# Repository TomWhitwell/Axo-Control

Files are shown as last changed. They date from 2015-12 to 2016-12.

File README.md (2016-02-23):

# Control board for Axoloti 

This is an unnoficial knob board for the [Axoloti Core board](http://www.axoloti.com/).  It is not authorised or approved by Axoloti. 

Quick demo video: https://www.instagram.com/p/BAqbNhdjmaf/   
Another demo video: https://www.youtube.com/watch?v=lhx-O6MQIug  

##BOM  
1 x PS2/3 analogue joystick, available from [Sparkfun](https://www.sparkfun.com/products/9032) or [Cool Components](https://www.coolcomponents.co.uk/thumb-joystick.html)  

6 x 10k Potentiometers
- 9mm vertical pots 
- Linear taper, any value from 5k to 50k should be fine
- D Shaft (or whatever is suitable for your knobs)
- Try: Bourns PTV09A-4020F-B103 or Alps RK09K1130C79
- Or Alpha 9mm from [Thonk](https://www.thonk.co.uk/shop/alpha-9mm-pots/) 
- NB: If you can't find the Joystick, there is a space for a 7th pot underneath

3 x 12mm square tactile switches
- Multicomp MCDTS2-4R is the right switch, but it seems to be a fairly standard layout 
- The board also has space for standard little 6mm tactile switches
- You can get keycaps for the Omron 12mm switches:Black: KTSC-21K, White: KTSC-21I, Yellow: KTSC-21Y, Red: KTSC-21R. (

4 x 1k Resistors for LEDs (use higher values - 5k to 10k if you have ultrabright LEDs) 

4 x 3mm LEDs

4 x 11mm M3 Hex Standoffs to connect the control board to the main Axoloti Core PCB

*NB: Ignore these headers: The way the board has come out, it's impossible to solder them in, and the board is perfectly strong without them.*  2 x 2 pin Female Header 571-215297-2 to mount on the back of the Control board to provide support by connecting to pins on the X3 and X4 headers. There is no electrical connection here. 

1 x 40 pin Female Header to mount on the Axoloti core 

1 x 40 pin Male Header to mount on the Control board

##STATUS 
January 2016: Board built, works well. OSHPark project here: https://oshpark.com/shared_projects/XJm2ysZW  
Video here: https://www.instagram.com/p/BAqbNhdjmaf/   
December 2015: Design completed for Rev1 board, prototypes ordered from OSH Park. Design, BOM, Layout NOT VERIFIED. 

##LICENSE 
This project is Open Hardware  
All hardware and software design in this project is Creative Commons licensed by Tom Whitwell: CC-BY-SA: Attribution / ShareAlike.  
If you use any work in this project, you should credit me, and you must republish any changes you make under the same license.  
This license does permit commercial use of these designs, but consider getting in touch before selling anything.  
This license does not include or imply any connection to the Axoloti project by Johannes Taelman.

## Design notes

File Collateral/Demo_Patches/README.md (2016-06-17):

Axoloti Control Demo Patches 

If you compile these 3 onto your SD card, set to load 1 automatically, you should be able to switch between the patches by pushing one of the tiny buttons on the back of the board. 

These are super rough but might be useful for someone. I think 1.axp requires the audio files from a Radio Music module SD card to work.

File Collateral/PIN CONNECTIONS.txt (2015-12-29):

ANALOG INS

PA0
PA1
PA2
PA3
PA4
PA5
PA6
PA7 

PWM LED OUTS 
PB0
PB1
PB8
PB9 

DIGITAL INS BUTTONS
PC0
PC1
PC2
PC3

UNUSED: 
PC5 - DIGI IN DIGI OUT 
PC4 - DIGI IN DIGI OUT ANALOG IN 
PB7 - DIGI IN DIGI OUT 
PB6 - DIGI IN DIGI OUT

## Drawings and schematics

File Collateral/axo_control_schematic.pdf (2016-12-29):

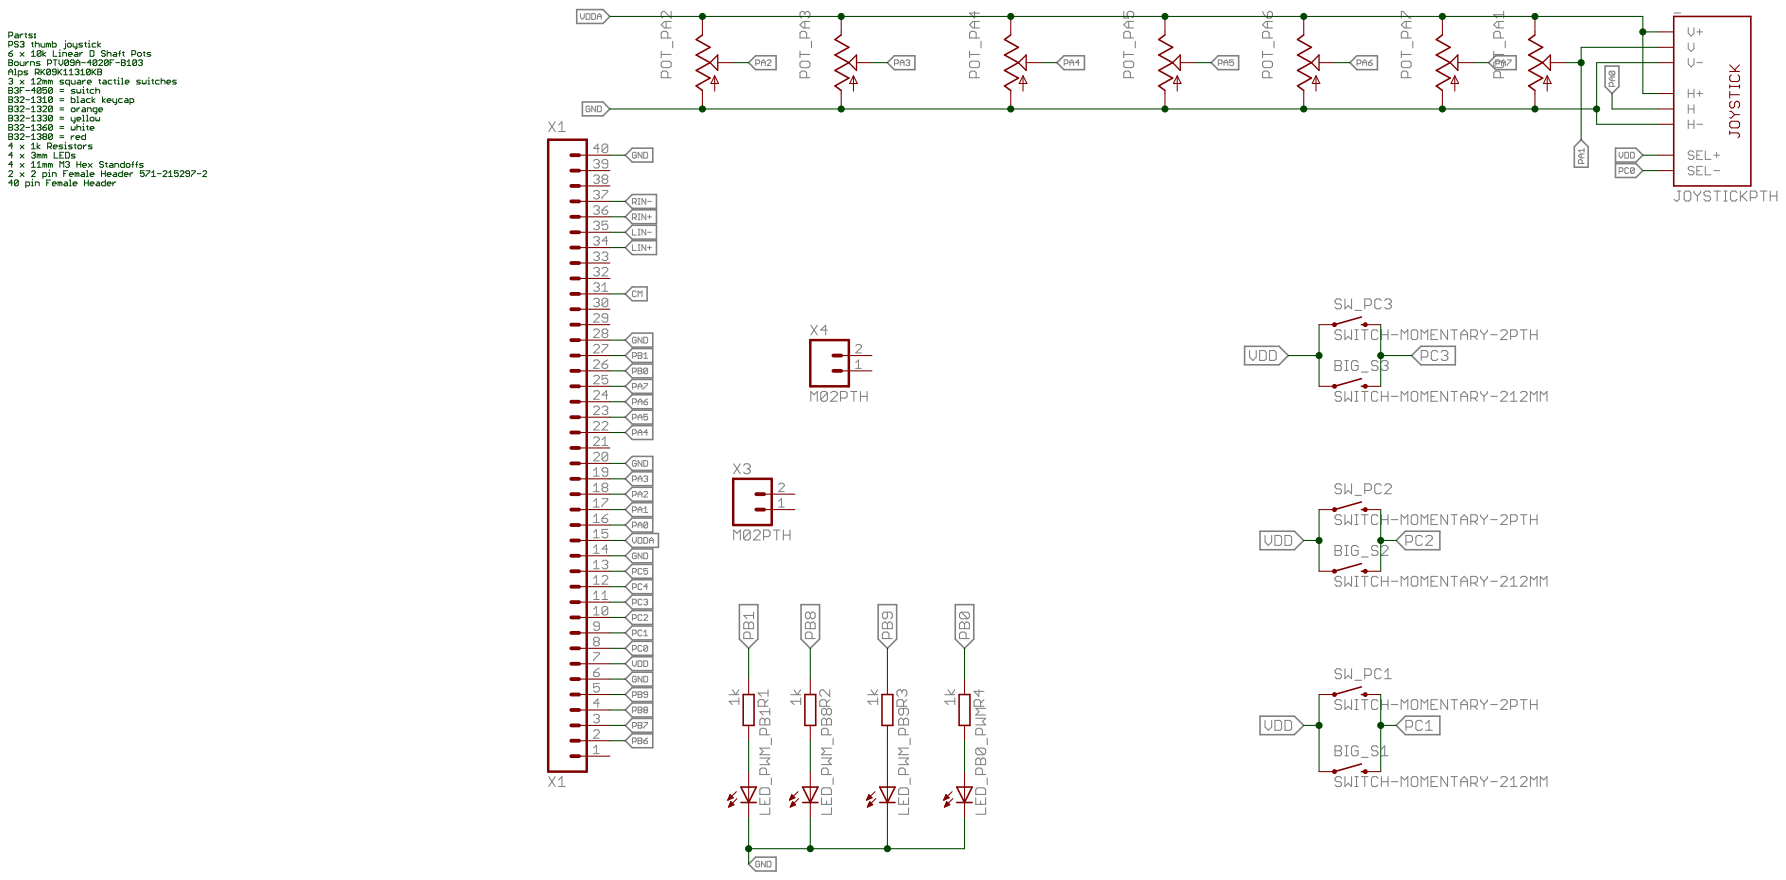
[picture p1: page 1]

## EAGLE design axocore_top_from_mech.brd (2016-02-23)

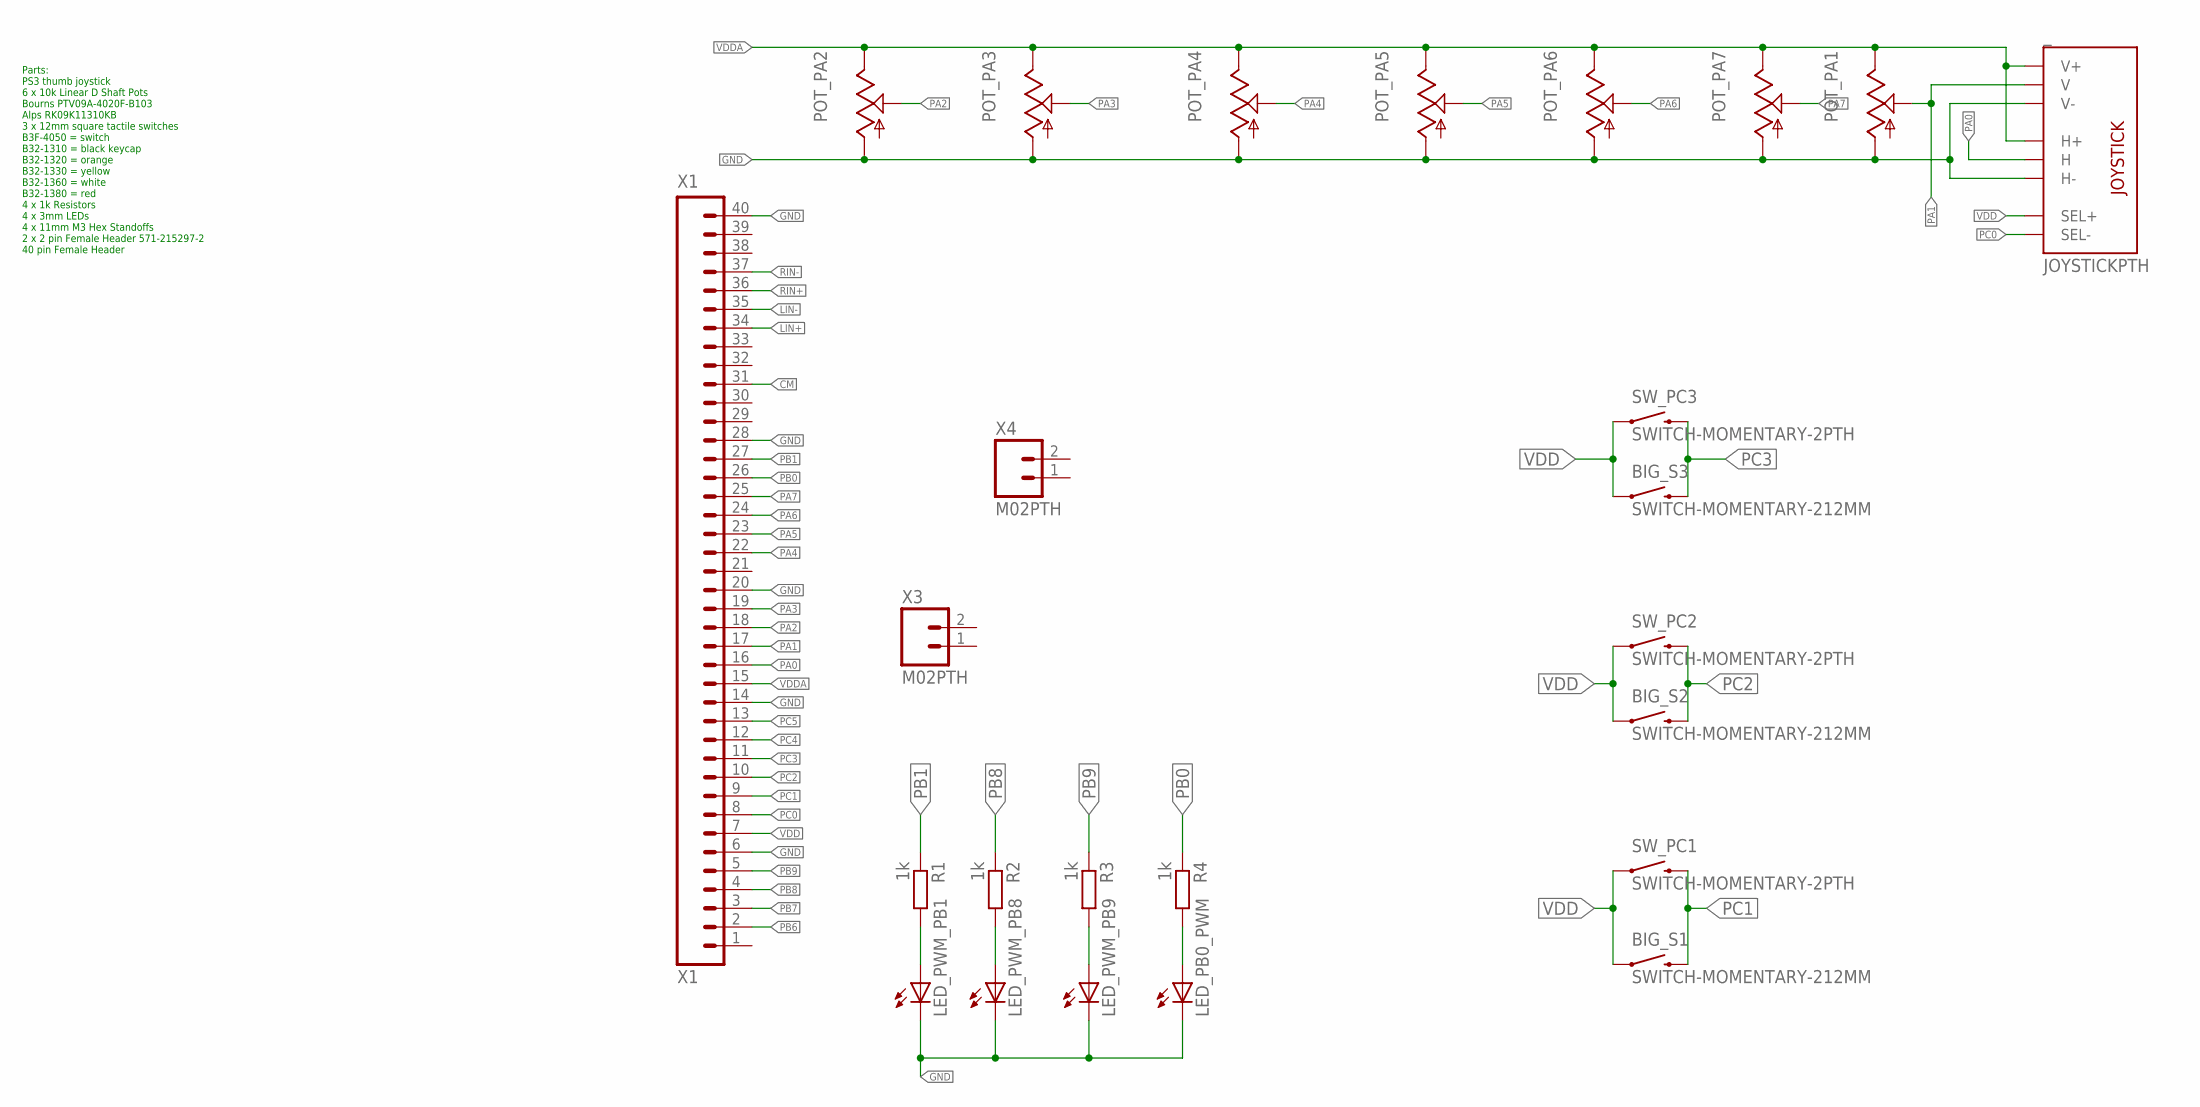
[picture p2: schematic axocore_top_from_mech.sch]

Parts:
BIG_S1, BIG_S2, BIG_S3: SWITCH-MOMENTARY-212MM; TACTILE-PTH-12MM
LED_PB0_PWM: LED3MM
LED_PWM_PB1, LED_PWM_PB8, LED_PWM_PB9: LED3MM
POT_PA1, POT_PA2, POT_PA3, POT_PA4, POT_PA5, POT_PA6, POT_PA7: 9MM_SNAP-IN_POT_; 9MM_SNAP-IN_POT
R1, R2, R3, R4: 1k; 7MM_RESISTOR
SW_PC1, SW_PC2, SW_PC3: SWITCH-MOMENTARY-2PTH; TACTILE-PTH
X1: X1; 1X40
X3, X4: M02PTH; 1X02
_: JOYSTICKPTH; JOYSTICK

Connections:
CM: X1.31
GND: LED_PB0_PWM.K (C), LED_PWM_PB1.K (C), LED_PWM_PB8.K (C), LED_PWM_PB9.K (C), POT_PA1.1 (A), POT_PA2.1 (A), POT_PA3.1 (A), POT_PA4.1 (A), POT_PA5.1 (A), POT_PA6.1 (A), POT_PA7.1 (A), X1.6, X1.14, X1.20, X1.28, X1.40, _.H3 (H-), _.V3 (V-)
LIN+: X1.34
LIN-: X1.35
unnamed: LED_PWM_PB1.A, R1.2
unnamed: LED_PWM_PB8.A, R2.2
unnamed: LED_PWM_PB9.A, R3.2
unnamed: LED_PB0_PWM.A, R4.2
PA0: X1.16, _.H2 (H)
PA1: POT_PA1.2 (S), X1.17, _.V2 (V)
PA2: POT_PA2.2 (S), X1.18
PA3: POT_PA3.2 (S), X1.19
PA4: POT_PA4.2 (S), X1.22
PA5: POT_PA5.2 (S), X1.23
PA6: POT_PA6.2 (S), X1.24
PA7: POT_PA7.2 (S), X1.25
PB0: R4.1, X1.26
PB1: R1.1, X1.27
PB6: X1.2
PB7: X1.3
PB8: R2.1, X1.4
PB9: R3.1, X1.5
PC0: X1.8, _.B2A (SEL-)
PC1: BIG_S1.3 (2), SW_PC1.3 (2), X1.9
PC2: BIG_S2.3 (2), SW_PC2.3 (2), X1.10
PC3: BIG_S3.3 (2), SW_PC3.3 (2), X1.11
PC4: X1.12
PC5: X1.13
RIN+: X1.36
RIN-: X1.37
VDD: BIG_S1.1, BIG_S2.1, BIG_S3.1, SW_PC1.1, SW_PC2.1, SW_PC3.1, X1.7, _.B1A (SEL+)
VDDA: POT_PA1.3 (E), POT_PA2.3 (E), POT_PA3.3 (E), POT_PA4.3 (E), POT_PA5.3 (E), POT_PA6.3 (E), POT_PA7.3 (E), X1.15, _.H1 (H+), _.V1 (V+)

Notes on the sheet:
Parts: PS3 thumb joystick 6 x 10k Linear D Shaft Pots Bourns PTV09A-4020F-B103 Alps RK09K11310KB 3 x 12mm square tactile switches B3F-4050 = switch B32-1310 = black keycap B32-1320 = orange B32-1330 = yellow B32-1360 = white B32-1380 = red 4 x 1k Resistors 4 x 3mm LEDs 4 x 11mm M3 Hex Standoffs 2 x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

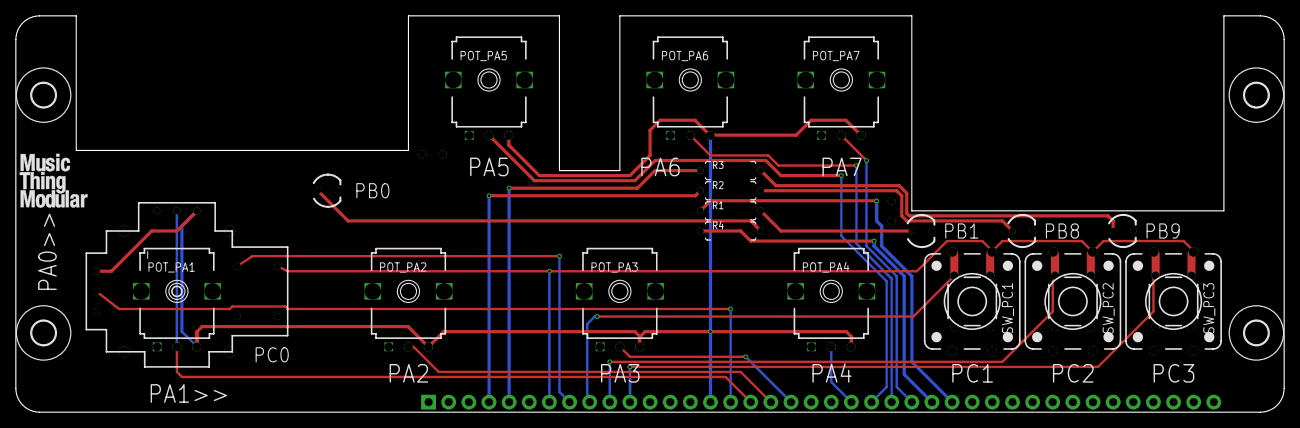
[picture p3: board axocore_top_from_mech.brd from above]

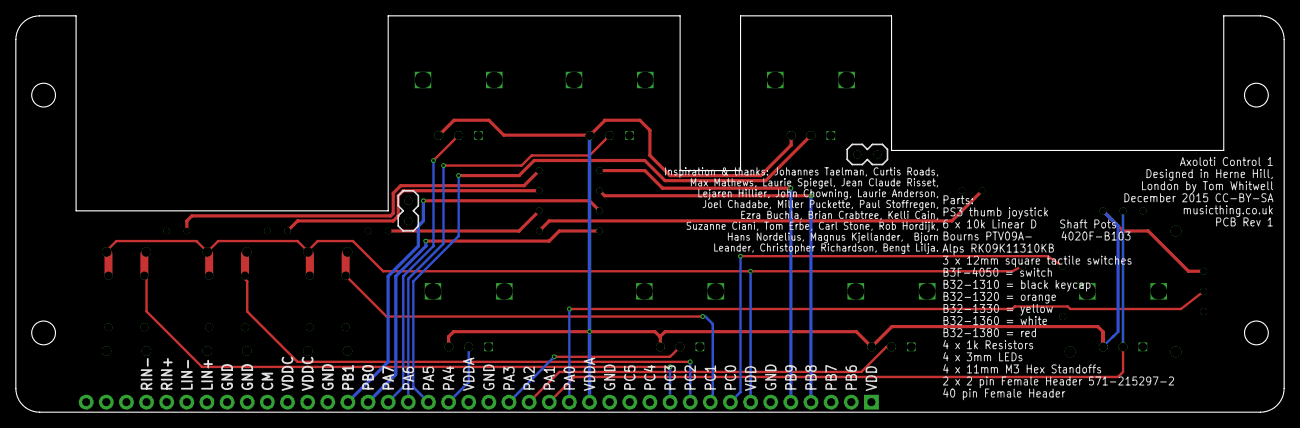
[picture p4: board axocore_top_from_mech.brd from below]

Board: 4 copper layers, 160.0 x 50.0 mm, 29 parts (2 on the bottom side), 23 nets.

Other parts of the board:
H1, H2, H4, H6: MOUNT-HOLE3.0; 3,0

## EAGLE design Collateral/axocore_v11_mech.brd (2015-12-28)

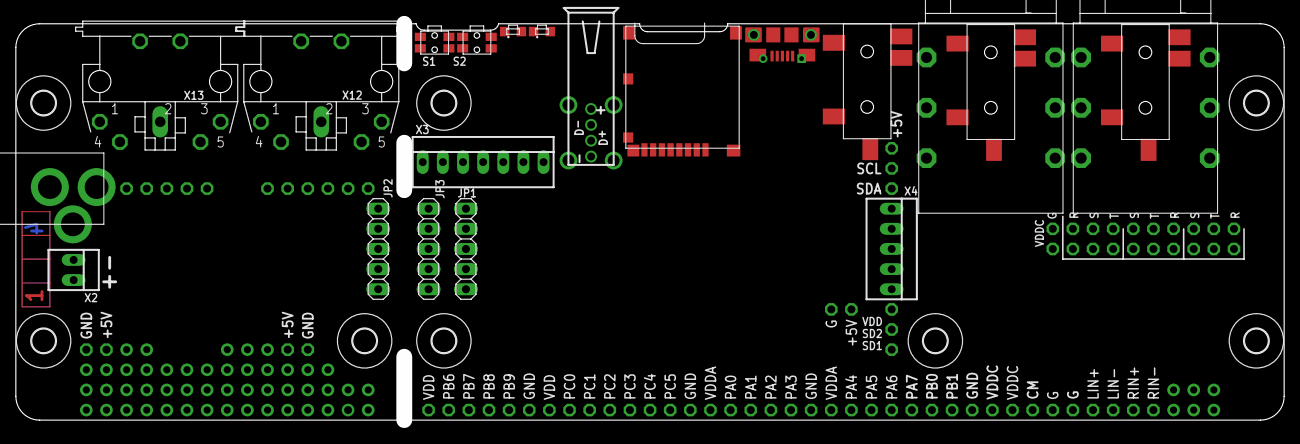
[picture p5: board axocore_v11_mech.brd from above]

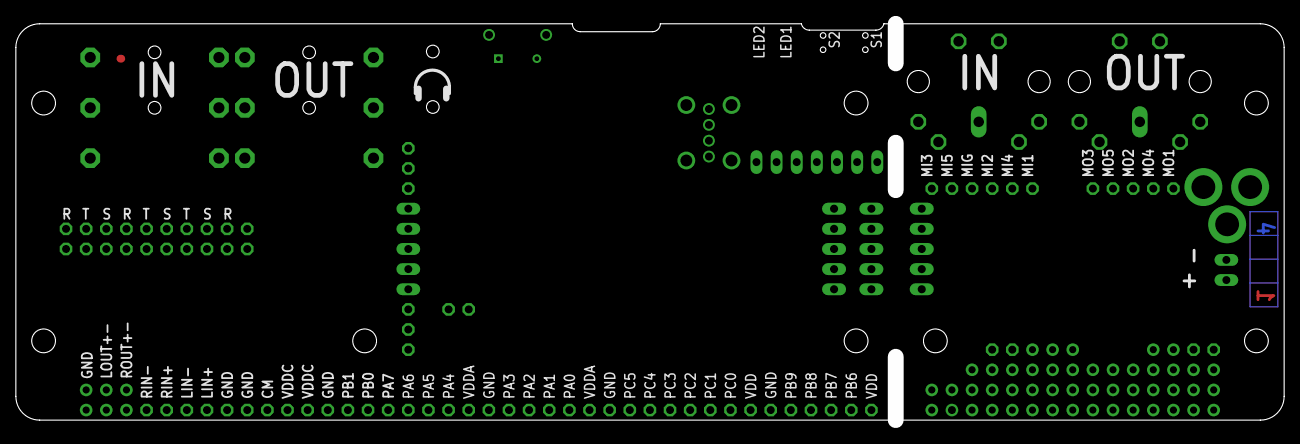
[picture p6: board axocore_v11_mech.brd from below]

Board: 2 copper layers, 160.0 x 50.0 mm, 109 parts (11 on the bottom side), 31 nets.

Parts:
D5: SML-A12 RED; SML-A12
D6: SML-A12 GREEN; SML-A12
H1, H2, H3, H4, H5, H6, H7, H8: MOUNT-HOLE3.0; 3,0
JP1: 1X05
JP2, JP3: NC; 1X05
S1, S2: EVQP7
TP1, TP66, TP77: VDDC; PROTOHOLE_NAMED
TP2: MI3; PROTOHOLE_NAMED
TP3: MI5; PROTOHOLE_NAMED
TP4: CM; PROTOHOLE_NAMED
TP5: MI1; PROTOHOLE_NAMED
TP6: MI4; PROTOHOLE_NAMED
TP7, TP59, TP63, TP67: G; PROTOHOLE_NAMED
TP8: MI2; PROTOHOLE_NAMED
TP9: MIG; PROTOHOLE_NAMED
TP10: MO3; PROTOHOLE_NAMED
TP11: MO1; PROTOHOLE_NAMED
TP12: MO5; PROTOHOLE_NAMED
TP13, TP57, TP58, TP60, TP61, TP62: GND; PROTOHOLE_NAMED
TP14: SD1; PROTOHOLE_NAMED
TP15: SD2; PROTOHOLE_NAMED
TP16, TP64, TP65: VDD; PROTOHOLE_NAMED
TP17: SDA; PROTOHOLE_NAMED
TP18: SCL; PROTOHOLE_NAMED
TP19, TP21, TP23, TP26, TP28, TP30: PROTOHOLE
TP20, TP29, TP36: S; PROTOHOLE_NAMED
TP22, TP27, TP34: R; PROTOHOLE_NAMED
TP24, TP25, TP32: T; PROTOHOLE_NAMED
TP31: T; PROTOHOLE
TP33: R; PROTOHOLE
TP35: S; PROTOHOLE
TP37: PA0; PROTOHOLE_NAMED
TP38: PA1; PROTOHOLE_NAMED
TP39: PA2; PROTOHOLE_NAMED
TP40: PA3; PROTOHOLE_NAMED
TP41: PA4; PROTOHOLE_NAMED
TP42: PA5; PROTOHOLE_NAMED
TP43: PA6; PROTOHOLE_NAMED
TP44: PA7; PROTOHOLE_NAMED
TP45: PB0; PROTOHOLE_NAMED
TP46: PB1; PROTOHOLE_NAMED
TP47: PB6; PROTOHOLE_NAMED
TP48: PB7; PROTOHOLE_NAMED
TP49: PB8; PROTOHOLE_NAMED
TP50: PB9; PROTOHOLE_NAMED
TP51: PC0; PROTOHOLE_NAMED
TP52: PC1; PROTOHOLE_NAMED
TP53: PC2; PROTOHOLE_NAMED
TP54: PC3; PROTOHOLE_NAMED
TP55: PC4; PROTOHOLE_NAMED
TP56: PC5; PROTOHOLE_NAMED
TP68, TP69, TP70, TP76: +5V; PROTOHOLE_NAMED
TP71, TP72: VDDA; PROTOHOLE_NAMED
TP73: MO4; PROTOHOLE_NAMED
TP74: MO2; PROTOHOLE_NAMED
TP75: LIN+; PROTOHOLE_NAMED
TP78: LIN-; PROTOHOLE_NAMED
TP79: RIN+; PROTOHOLE_NAMED
TP80: RIN-; PROTOHOLE_NAMED
USB1: FCI 73725-0110BLF; USB_A_VERTICAL_PTH
X1: 2.1MMJACKTHM; PJ-102A
X2: 22-23-2021
X3: 22-23-2071
X4: NC (22-23-2051); 22-23-2051
X5, X8: NC (35RASMT4); 35RASMT4BHNTR
X6, X7: NMJ6HFD2; JACK63
X9: 35RASMT4; 35RASMT4BHNTR
X10: ZX62D-B-5P8
X11: MOLEX_502774
X12, X13: MAB5SH

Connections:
+5V: JP2.1, JP3.1, TP68.P$1, TP69.P$1, TP70.P$1, TP76.P$1, X3.3
BLINN: TP24.P$1, TP26.P$1, X5.P3, X6.T
BLOUTP: TP31.P$1, TP32.P$1, X7.T, X8.P3
BRINN: TP27.P$1, TP28.P$1, X5.P2, X6.R
BROUTP: TP33.P$1, TP34.P$1, X7.R, X8.P2
GND: JP1.3, JP2.5, JP3.5, TP7.P$1, TP13.P$1, TP57.P$1, TP58.P$1, TP59.P$1, TP60.P$1, TP61.P$1, TP62.P$1, TP63.P$1, TP67.P$1, TP74.P$1, X1.RING, X2.1, X3.1, X4.1, X13.2, X13.PE, X13.PE@
HSHIELD: USB1.P$3, USB1.P$4
INSGND: TP29.P$1, TP30.P$1, X5.P1, X6.S
LHP: TP21.P$1, TP22.P$1, X9.P3
LIN+: TP75.P$1, TP79.P$1
MI1: TP5.P$1, X12.1
MI2: TP8.P$1, X12.2
MI3: TP2.P$1, X12.3
MIDIIN4: TP6.P$1, X12.4
MIDIIN5: TP3.P$1, X12.5
MIDIOUT4: TP73.P$1, X13.4
MIDIOUT5: TP12.P$1, X13.5
MIG: TP9.P$1, X12.PE, X12.PE@
MO1: TP11.P$1, X13.1
MO3: TP10.P$1, X13.3
MONOOUT: TP19.P$1, TP20.P$1, X9.P1
OUTSGND: TP35.P$1, TP36.P$1, X7.S, X8.P1
PB10_USART3TX: X3.2, X4.5
PG9_USART6RX: JP2.3, JP3.3
PG14_USART6TX: JP2.4, JP3.4
RHP: TP23.P$1, TP25.P$1, X9.P2
VBUSEND: JP2.2, JP3.2
VDD: JP1.1, S1.P$2, S2.P$2, TP16.P$1, TP64.P$1, TP65.P$1
VDDA1: TP71.P$1, TP72.P$1
VDDC: TP1.P$1, TP66.P$1, TP77.P$1
VINJACK1: X1.TIP, X2.2

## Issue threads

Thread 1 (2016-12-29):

Axoloti control board schematics

Thierry-Cheverney, 2016-12-29:
Hello,
I am looking for the Axoloti Control Board Shematics and BOM.
I got the Tom Whittwell GitHub account link from Thonk in order to get these documents.
Thanks for answers. Thierry

TomWhitwell, 2016-12-29:
Just added a schematic for you: https://github.com/TomWhitwell/Axo-Control/blob/master/Collateral/axo_control_schematic.pdf

Thierry-Cheverney, 2016-12-31:
Thanks very much for your help. Thierry

Closed 2016-12-29.

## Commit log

2015-12-24 getting started
    [axoloti_knobs.brd, axoloti_knobs.sch, axoloti_sliders.brd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]
2015-12-26 full sized board
    [axoloti_knobs.brd]
2015-12-26 full width board
    [axoloti_knobs.brd, axoloti_knobs.sch]
2015-12-28 added reference board template
    [axocore_v11_mech.brd, axoloti_knobs_bottom.brd, axoloti_knobs_bottom.sch]
2015-12-28 new version on proper layout
    [axocore_top_from_mech.brd, axocore_top_from_mech.sch]
2015-12-28 finalised layout, starting routing
    [axocore_top_from_mech.brd, axocore_top_from_mech.sch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]
2015-12-29 Completed routing
    [axocore_top_from_mech.brd, axocore_top_from_mech.sch, axoloti_knobs.brd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]
2015-12-31 Rev 1 Complete and sent to OSHPark
    [axocore_top_from_mech.brd, axocore_top_from_mech.sch, axocore_v11_mech.brd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]
2016-02-23 Enlarged text on Eagle Silkscreen Layer, NOT on fancy gerber edited in Cenon
    [axocore_top_from_mech.brd]
2016-12-29 Add schematic

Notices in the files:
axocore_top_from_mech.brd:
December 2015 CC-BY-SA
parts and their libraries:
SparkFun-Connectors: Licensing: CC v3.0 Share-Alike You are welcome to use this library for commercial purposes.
